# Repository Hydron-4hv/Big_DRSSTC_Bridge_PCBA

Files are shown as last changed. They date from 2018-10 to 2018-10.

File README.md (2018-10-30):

# Big_DRSSTC_Bridge_PCBA
PCBA for 2x IGBT brick bridge for my 160mm DRSSTC

This is a PCBA I have designed to accomodate 2x half-bridge IGBTs, either CM300DY-24H or SKM200GB125D (or any which are dimensionally and pinout compatible). The footprints have enlarged pads to accomodate the difference between the CM300s and SKM200s - I only have a couple of CM300s so if I manage to blow them up I'd like flexibility for replacement!

As well as the IGBTs it allows for a variety of bus/decoupling capacitors and bleed resistors:
- 2x 75mm dia. electrolytic capacitors, in series, with bleed resistors. These will need a short external jumper between the innermost mounting holes (would have lost too much copper area if I'd done it on the PCBA).
- 2x RBPS (or similar sized) IGBT snubber capacitors, mounted directly to the IGBT terminals.
- 2x smaller film capacitors with 22.5mm lead spacing.
- 6x 57.5mm * 35mm film capacitors, with 4 pins each at 52.5mm spacing. These are designed to take the bulk of the ripple current, and should fit a variety of 40uF/900-1100V capacitors that are coming up in bulk lots on ebay in europe. In my case I will be using Kemet C4AEOBW5400A3NJs.
- 6x small HV MLCCs in 1812 and 1825 packages. Added as I have some of these available to use, but may not be very necessary/helpful on a coil using IGBT bricks rather than fast TO-247 devices.
- 2x MMC bleed resistors, in series between the two half-bridge outputs.

This board is designed to go with a matching gate drive connector PCBA, see my other repo for this.

As it's cheapest and easiest to get 2 layer 1oz copper PCBs, I have made sure everything is mirrored around the centre of the PCB, allowing for a stack of an odd number of boards, with every second one flipped, to be made and used as one "multi-layer" PCBA. This both reduces the copper resistance and also the inductance of the bridge. I'll be trying this out with a JLCPCB order of 5x0.8mm PCBs for a 4mm thick stack costing ~$25 USD. For people who don't care about the cost ideally it'd be done with 1 PCB of 2oz+ and 3.2mm thickness for rigidity.

Note: See Manufacturing/Reference output folders for gerbers, schematic PDFs, STEP files etc.

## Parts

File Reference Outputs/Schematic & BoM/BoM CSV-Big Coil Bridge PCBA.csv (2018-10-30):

Designator | Comment | Description | Fitted | Footprint | LibRef | Quantity
C1, C2 | 885012209028 | Electrolytic capacitor | Fitted | PEH200YV447BMB2 | Capacitor_Elec | 2
C3, C4, C5, C6, C7, C8 |  |  | Fitted | C4AEOBW5400A3NJ | Capacitor | 6
C9, C10 | RBPS_Snubber_Capacitor_Mech_only |  | Fitted | RBPS_R4_OUTLINE | RBPS_Snubber_Capacitor_Mech_only | 2
C11, C12, C13, C14, C15, C16, C17, C18 | Capacitor |  | Fitted | 1825C, B32653A0224, 1812C | Capacitor | 8
Q1, Q2 | DUAL_IGBT_BRICK | IGBT, DUAL, BRICK | Fitted | CM300/SKM200_DUAL_FOOTPRINT_2 | DUAL_IGBT_BRICK | 2
R1, R2, R3, R4 | Resistor |  | Fitted | Res_Axial_0.6in | Resistor | 4

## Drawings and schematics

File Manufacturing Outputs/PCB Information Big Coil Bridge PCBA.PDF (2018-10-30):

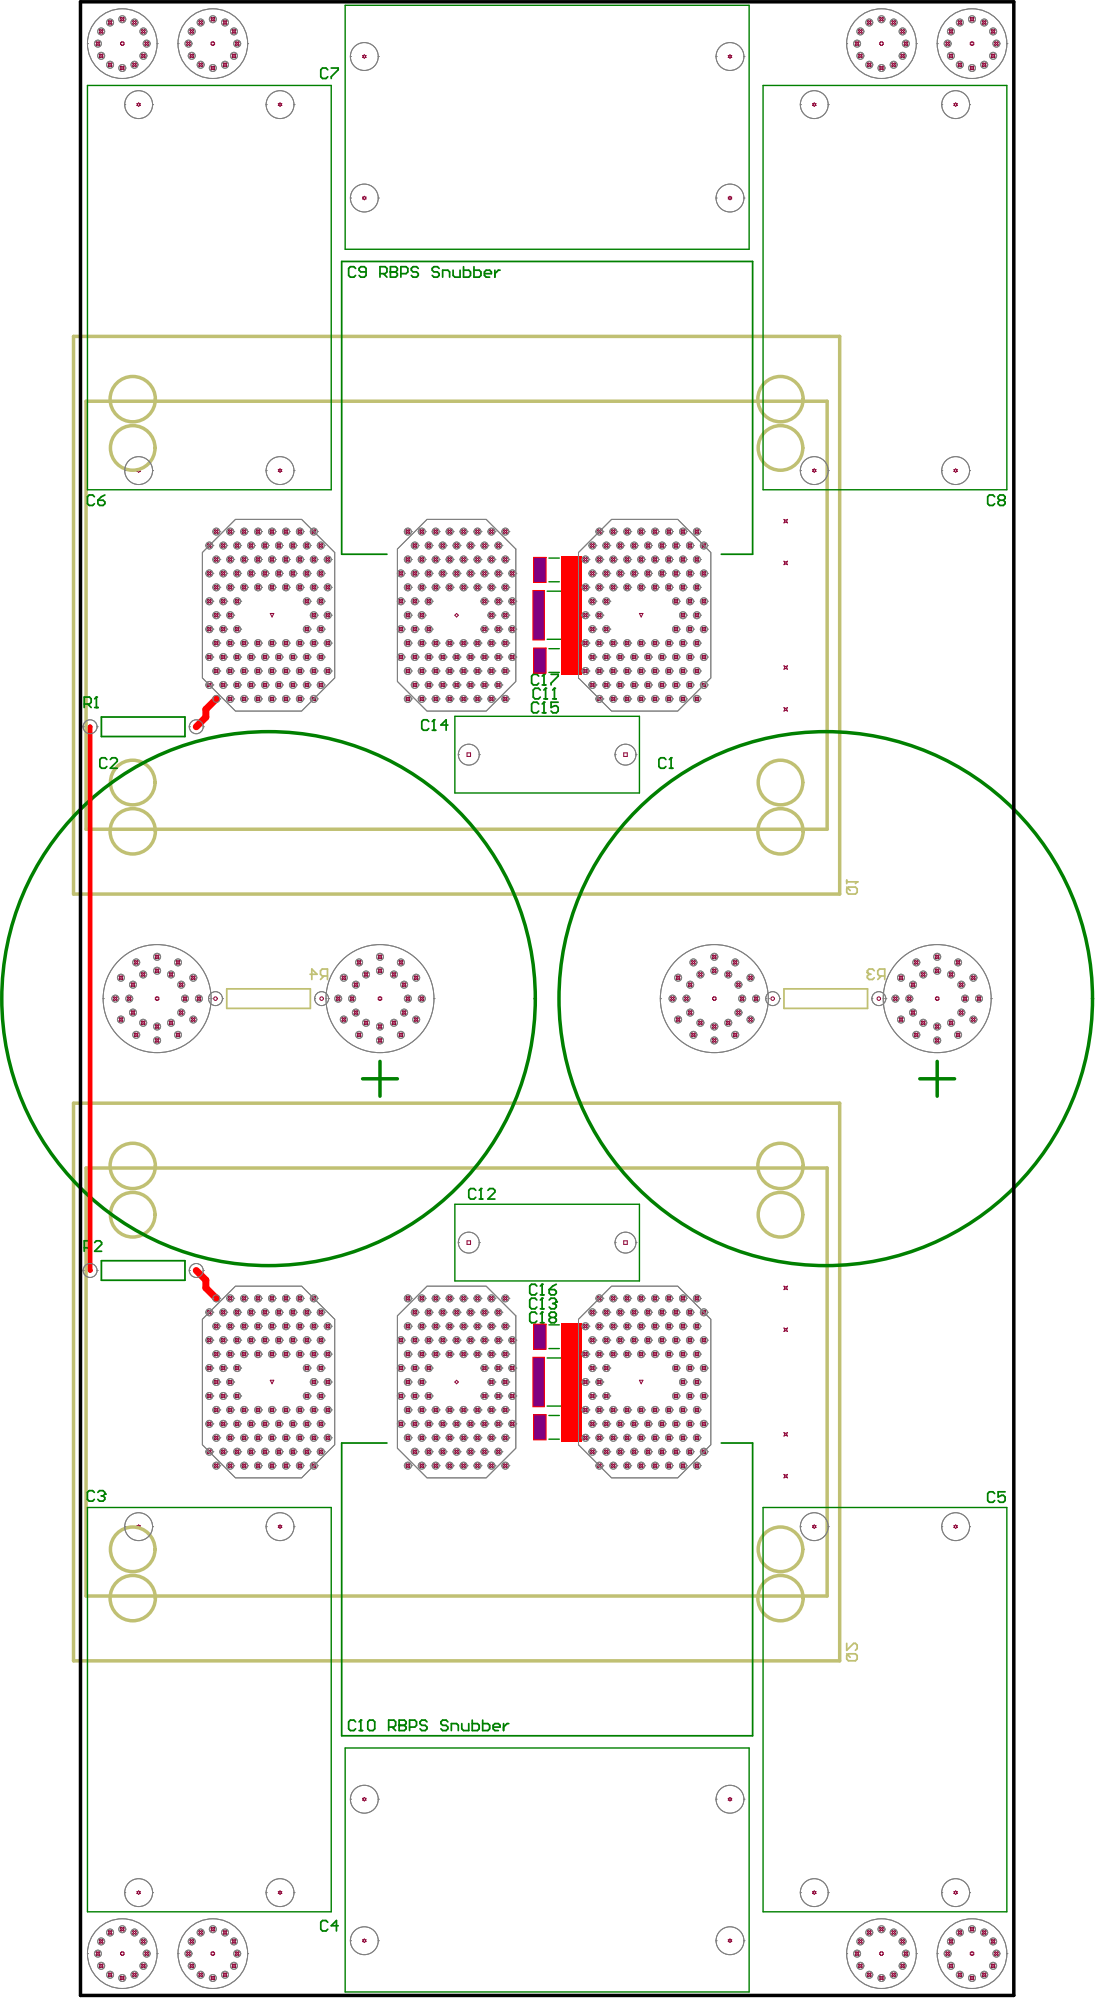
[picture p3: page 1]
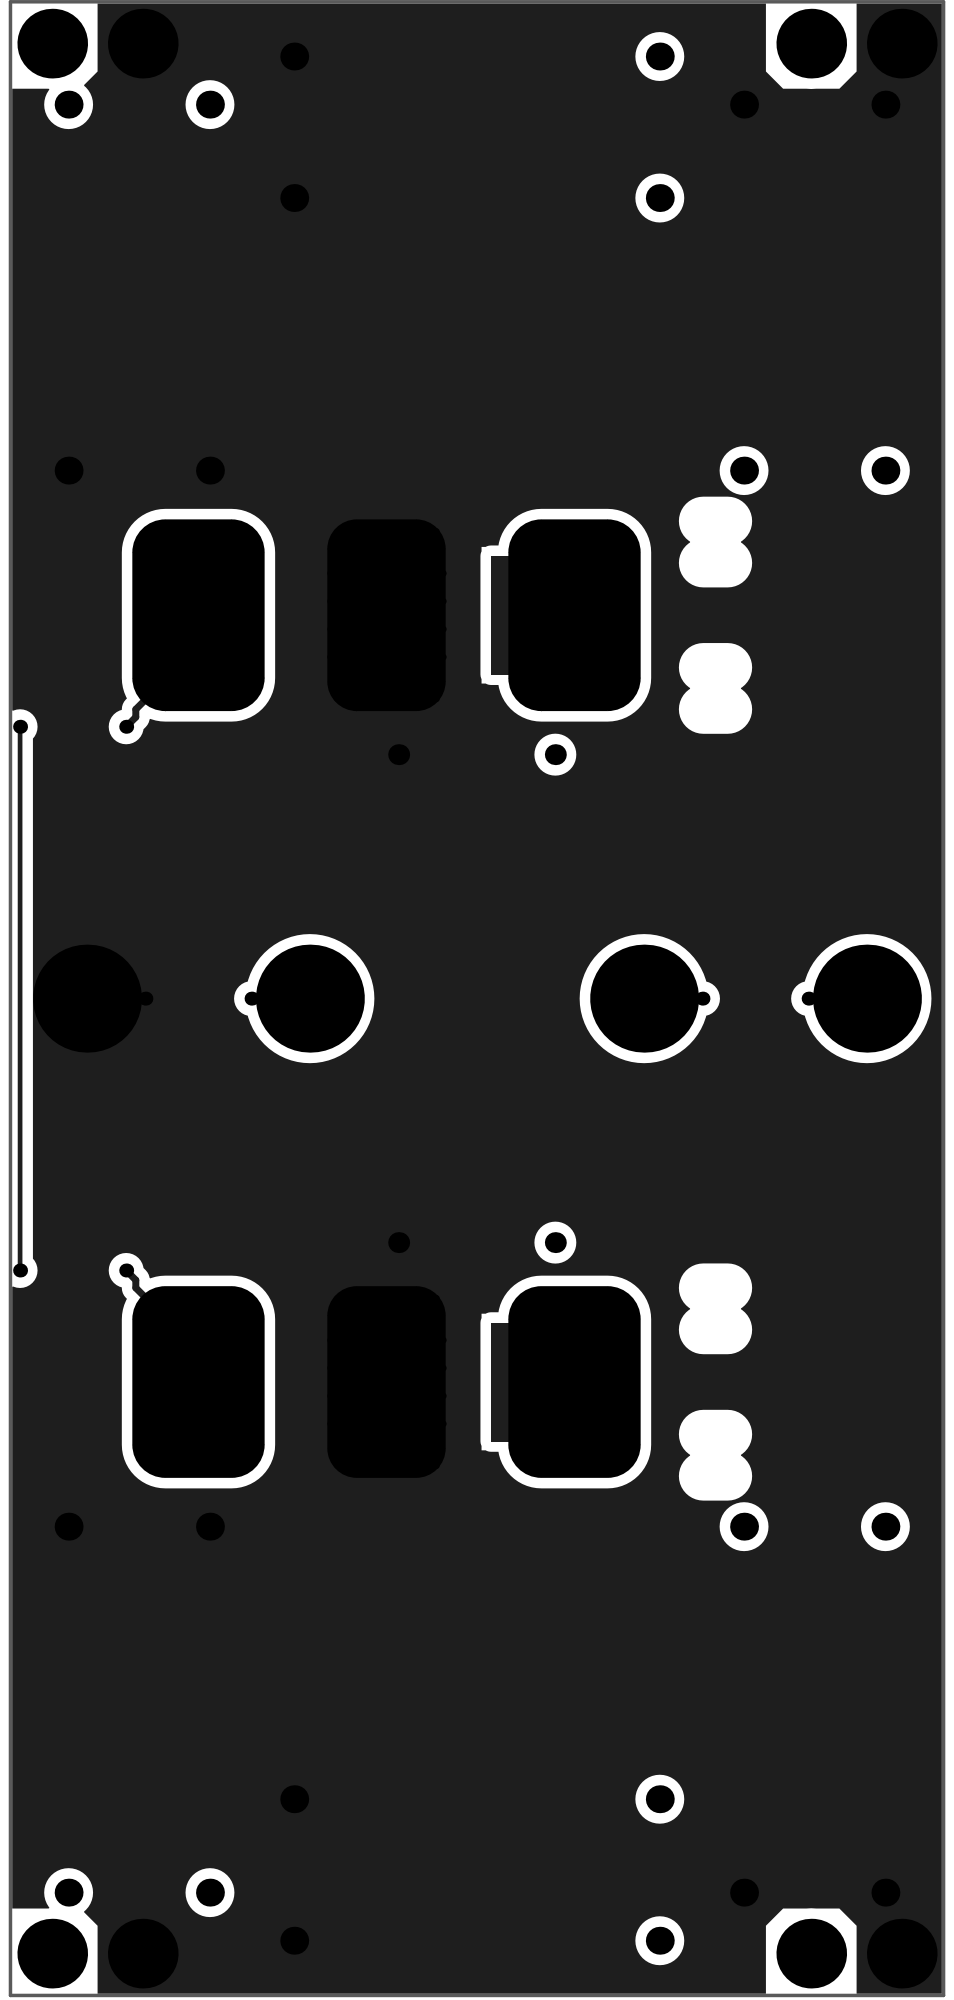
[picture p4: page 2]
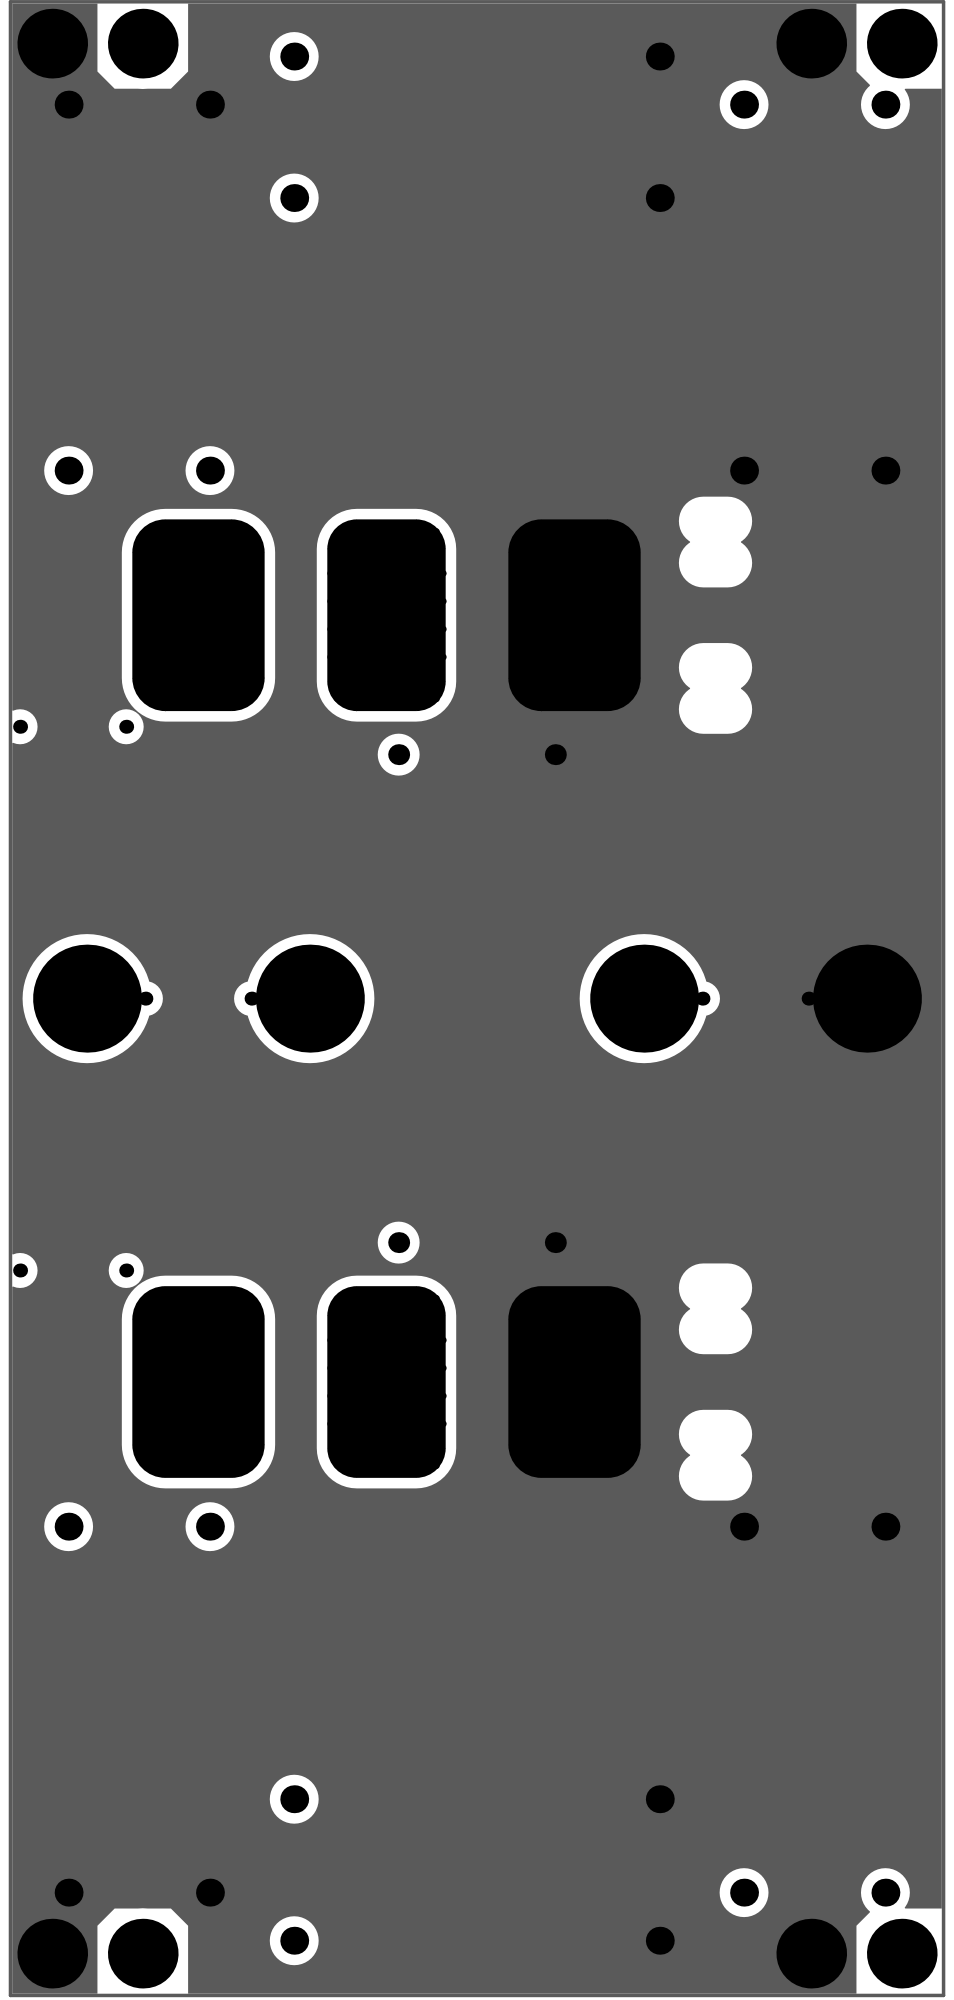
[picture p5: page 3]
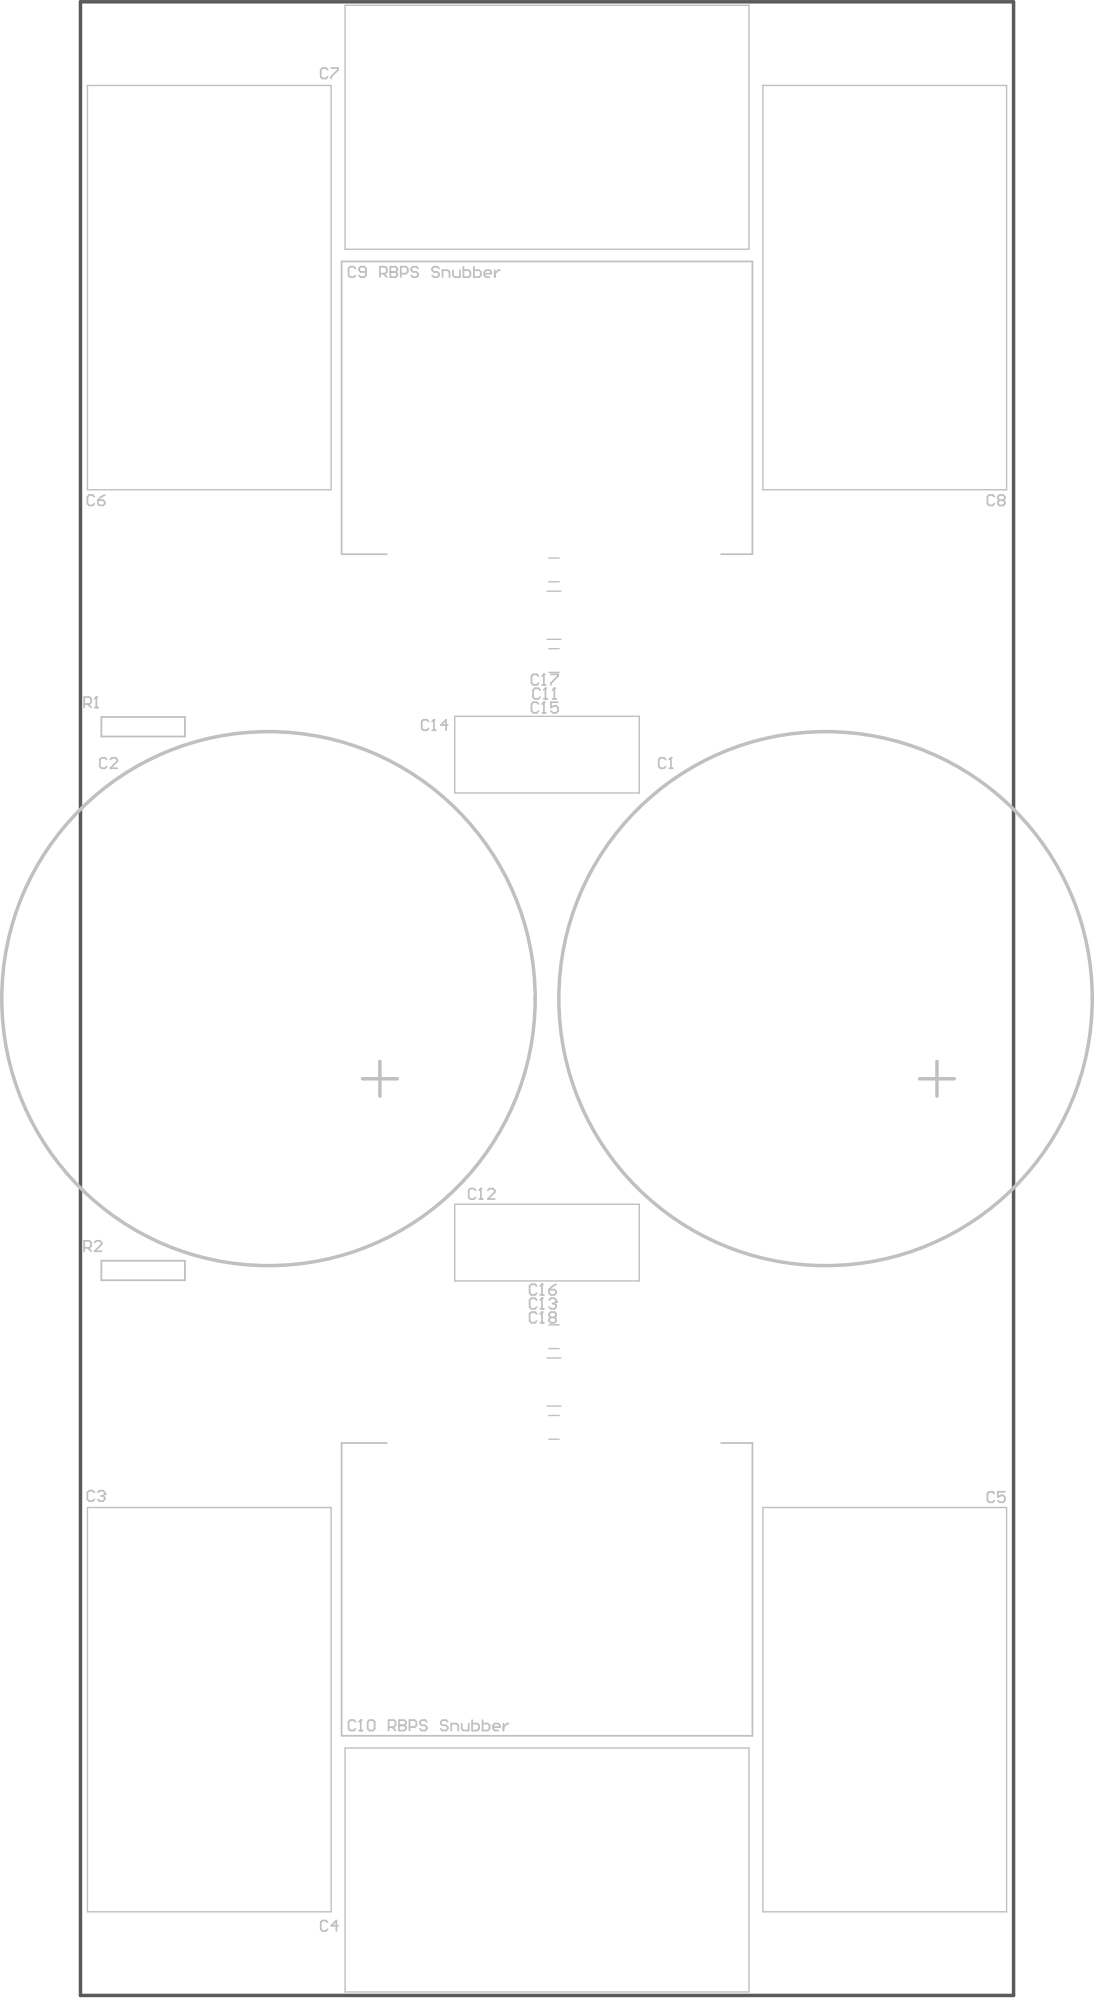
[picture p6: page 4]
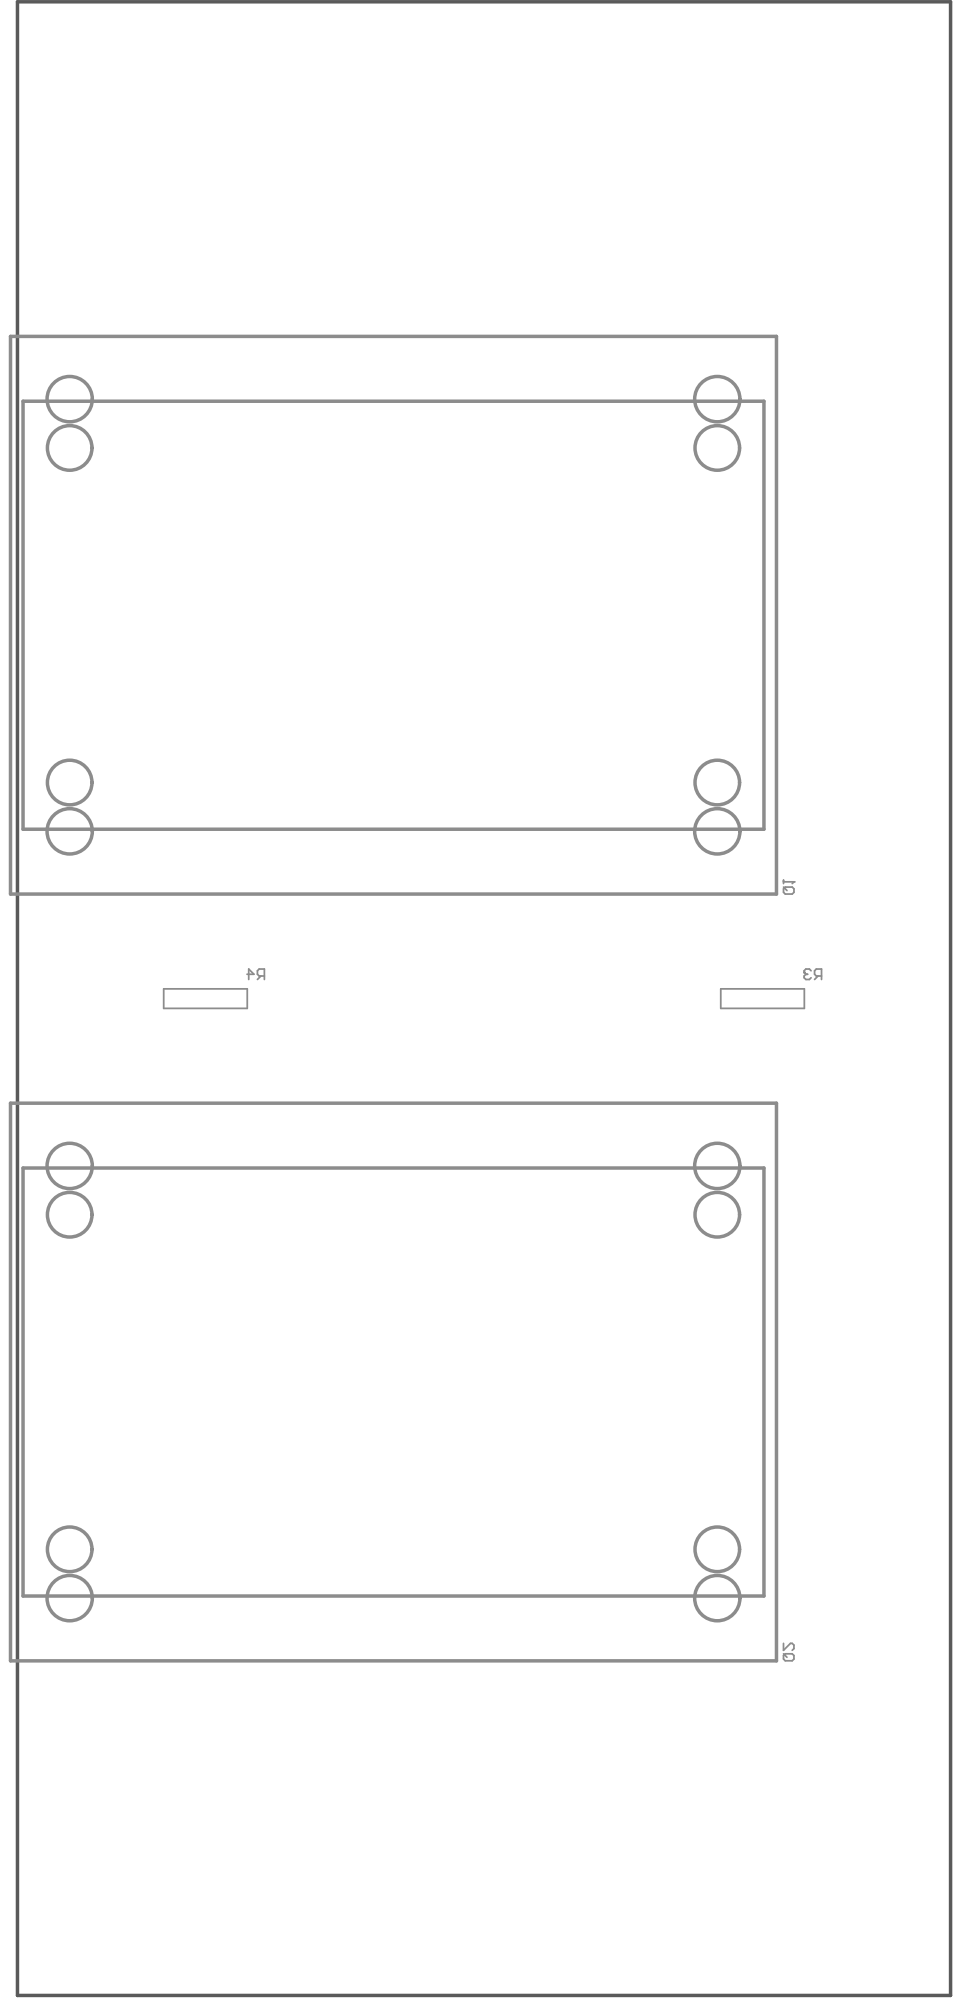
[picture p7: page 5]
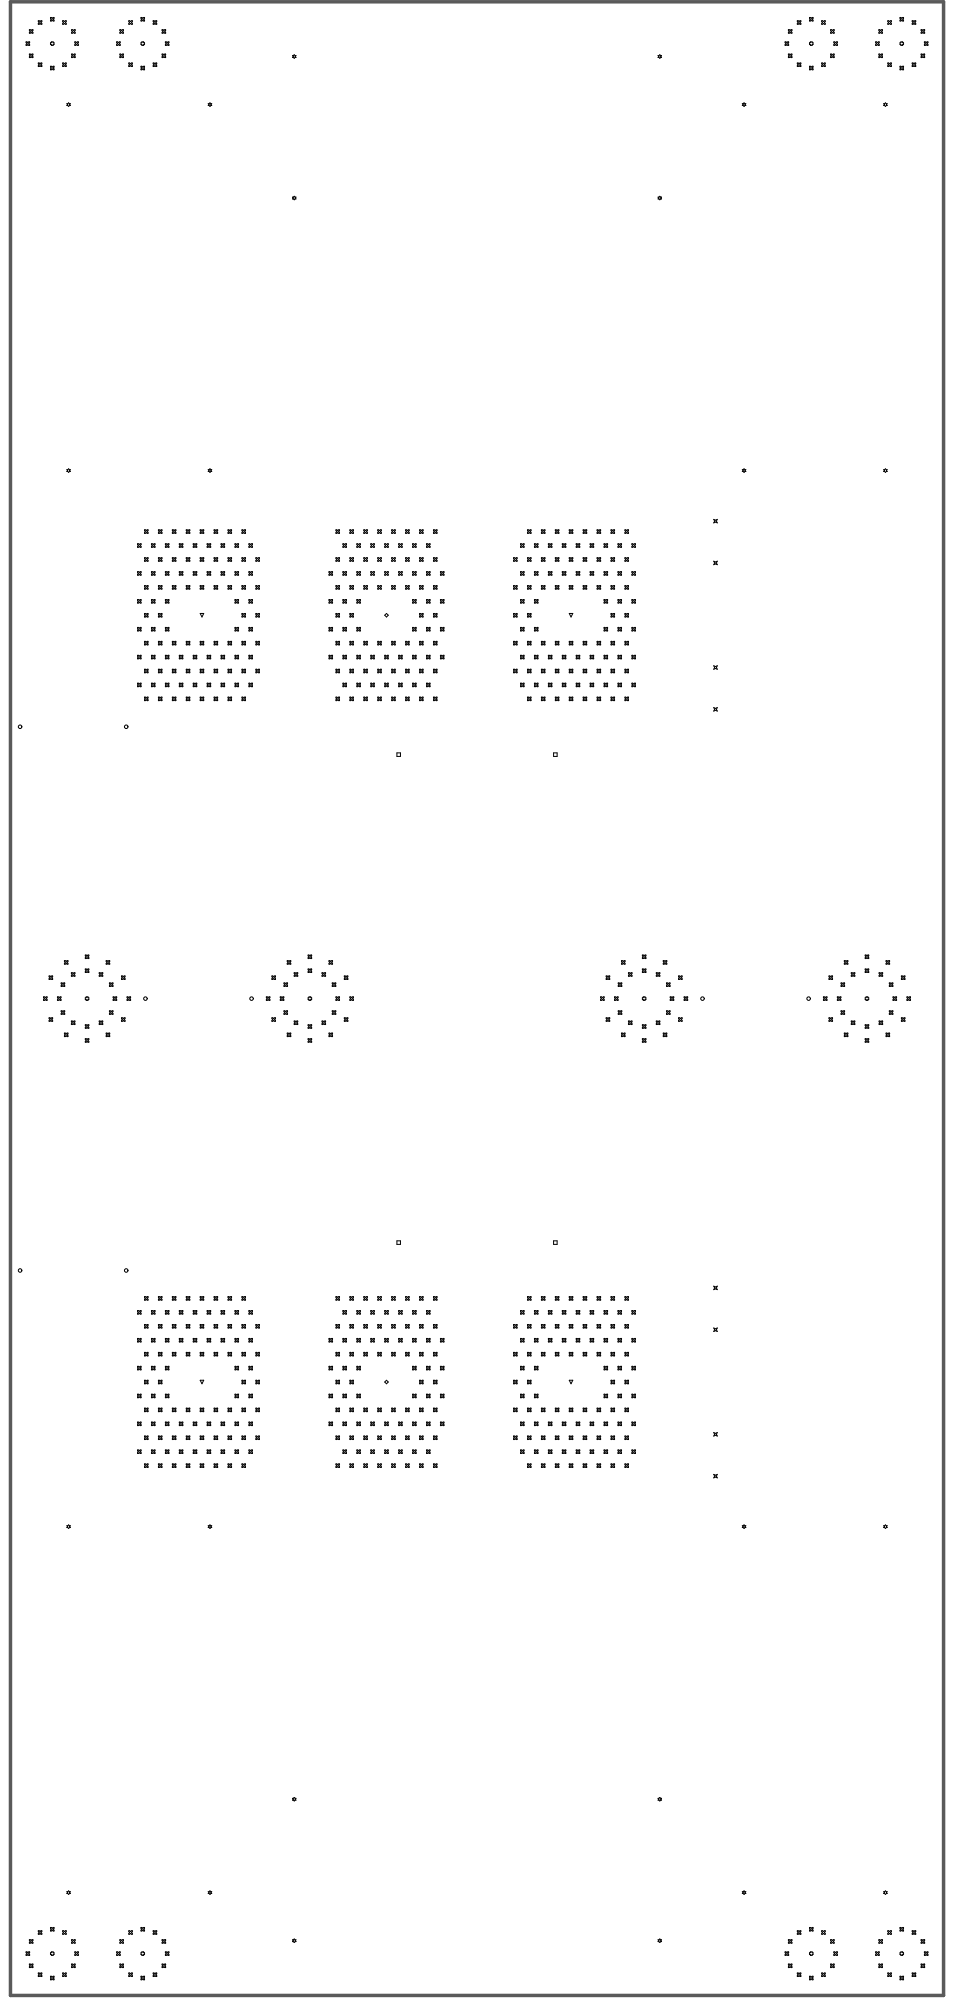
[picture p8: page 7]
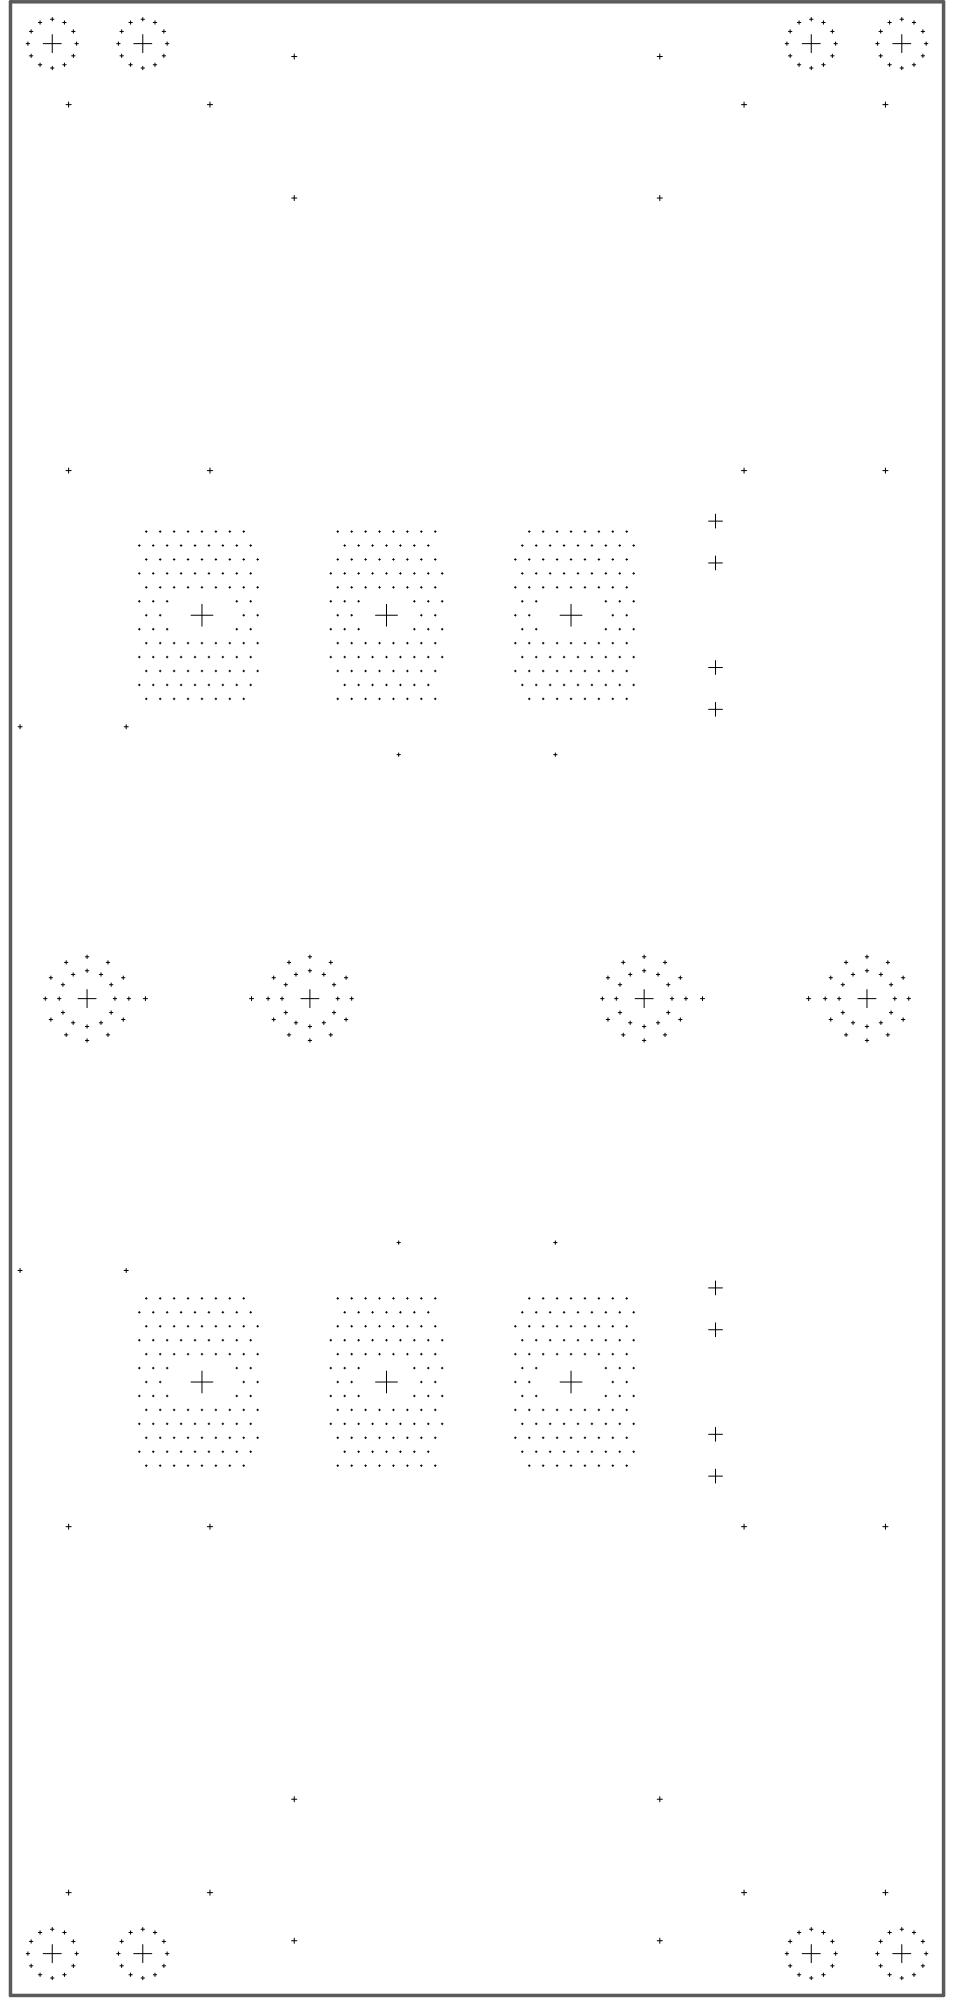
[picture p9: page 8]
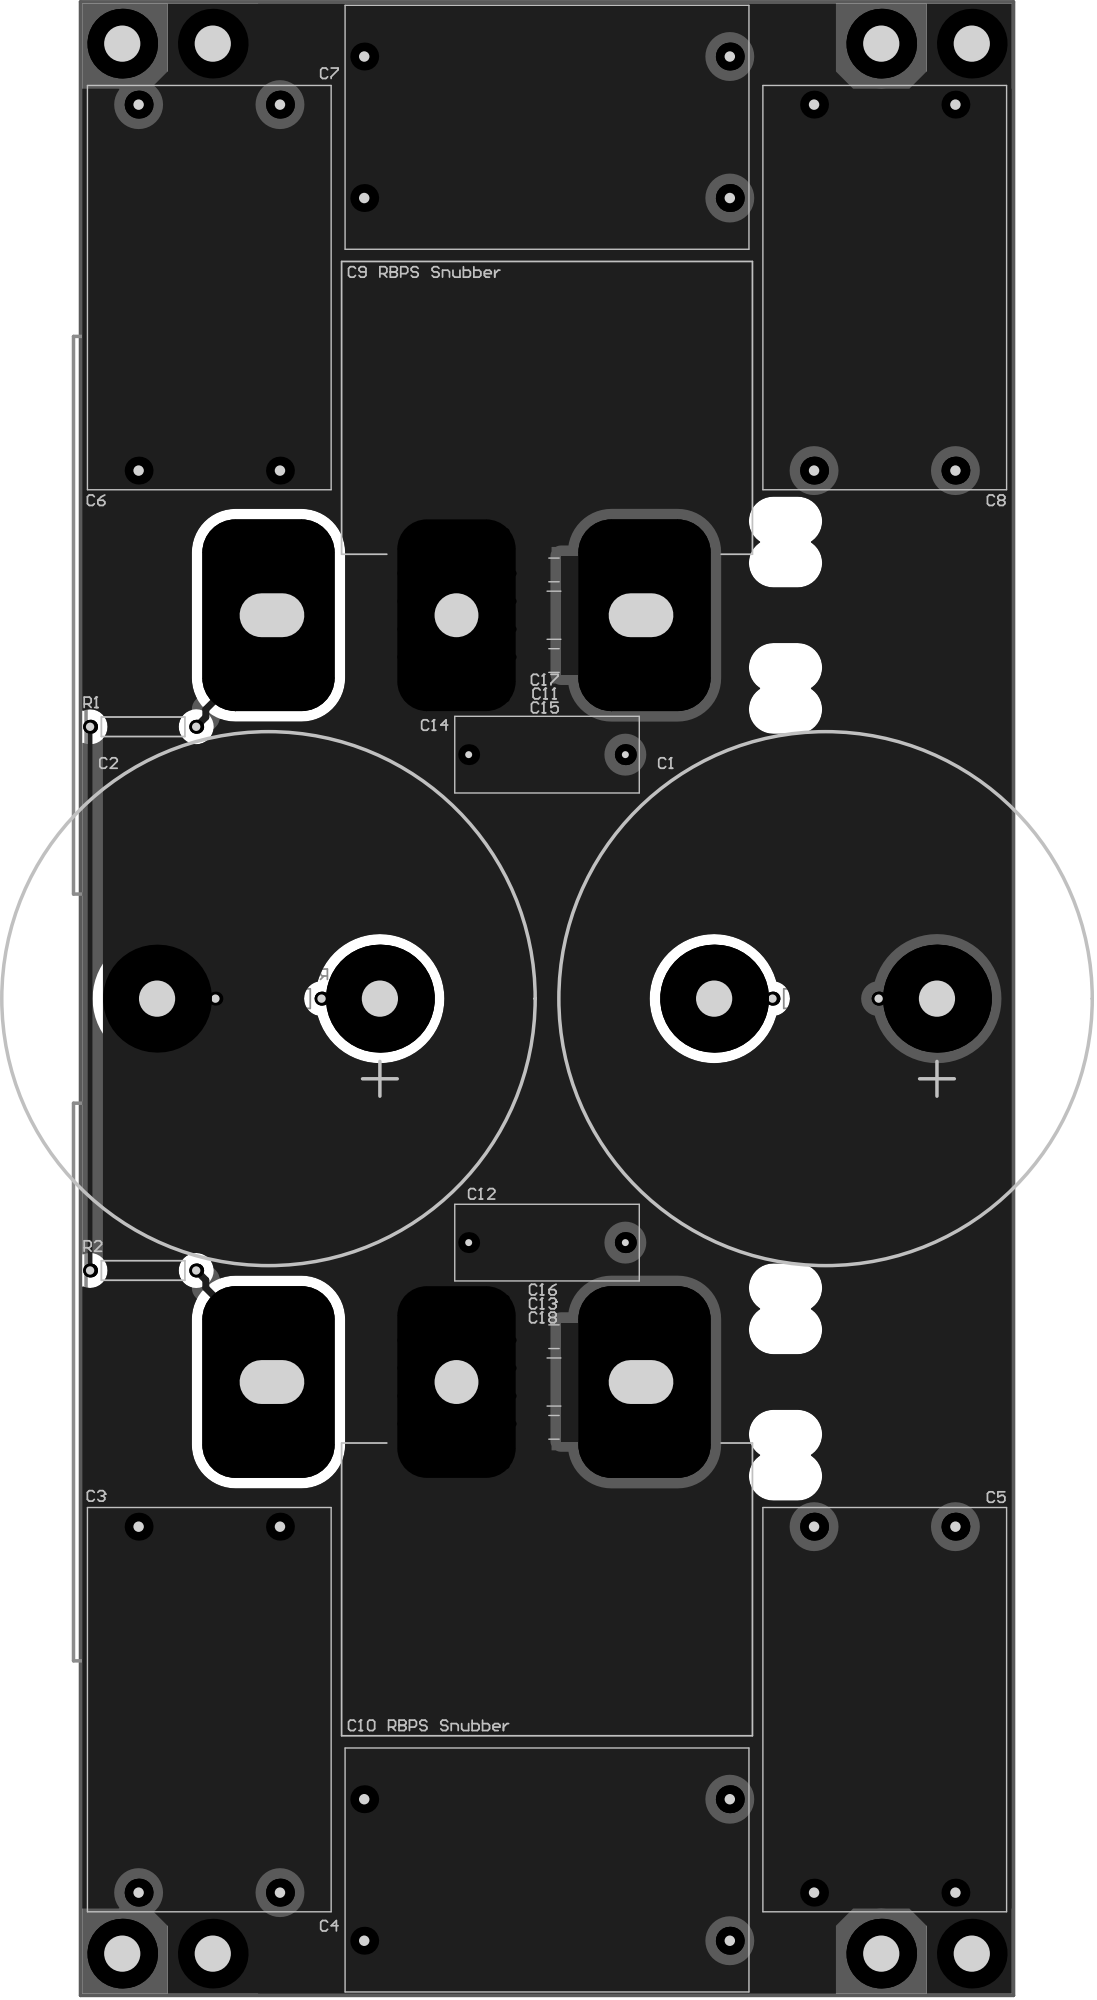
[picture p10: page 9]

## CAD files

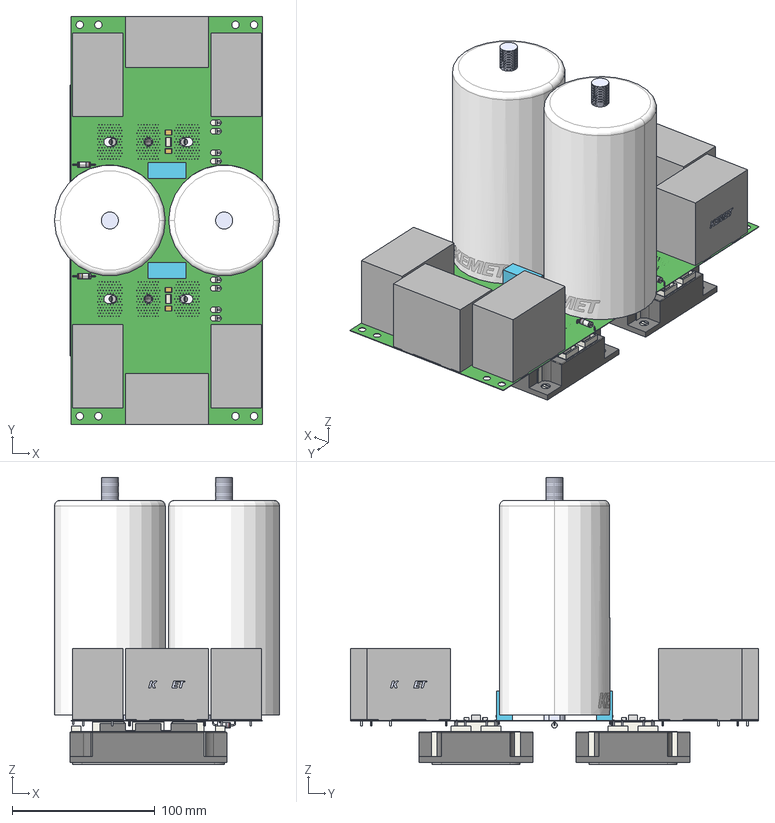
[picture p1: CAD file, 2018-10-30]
Reference Outputs/Mechanical/Export STEP Model of complete PCB_Big Coil Bridge PCBA-([No Variations]).step
157.6 x 286.0 x 200.9 mm
BoardBig_Coil_Bridge_PCBA_2
Open_CASCADE_STEP_translator_6.8_4.1.1 x 4
Open_CASCADE_STEP_translator_6.8_4.1.2 x 4
Open_CASCADE_STEP_translator_6.8_4.2.1 x 4
Extruded x 8
User_Library-Resistor_Carvao_2W_leed x 4
User_Library-Resistor_Carvao_2W_leed1 x 4
User_Library-Resistor_Carvao_2W_Cylinder003 x 4
User_Library-Resistor_Carvao_2W_Cylinder004 x 4
User_Library-Resistor_Carvao_2W_Torus x 4
User_Library-Resistor_Carvao_2W_Torus001 x 4
User_Library-Resistor_Carvao_2W_fx_1 x 4
User_Library-Resistor_Carvao_2W_fx_2 x 4
User_Library-Resistor_Carvao_2W_fx_3 x 4
User_Library-Resistor_Carvao_2W_fx_tol x 4
User_Library-Resistor_Carvao_2W_Cylinder005 x 4
User_Library-Resistor_Carvao_2W_Cylinder006 x 4
User_Library-Resistor_Carvao_2W_Cylinder007 x 4
User_Library-Resistor_Carvao_2W_Fillet x 4
User_Library-Resistor_Carvao_2W_Fillet001 x 4
C4AEOBW5400A3NJ x 6
Can_21 x 2
Oval_Terminal_21 x 4
Stud x 2
User_Library-IGBT_CM600DY-12NF x 2
99437A165 x 6

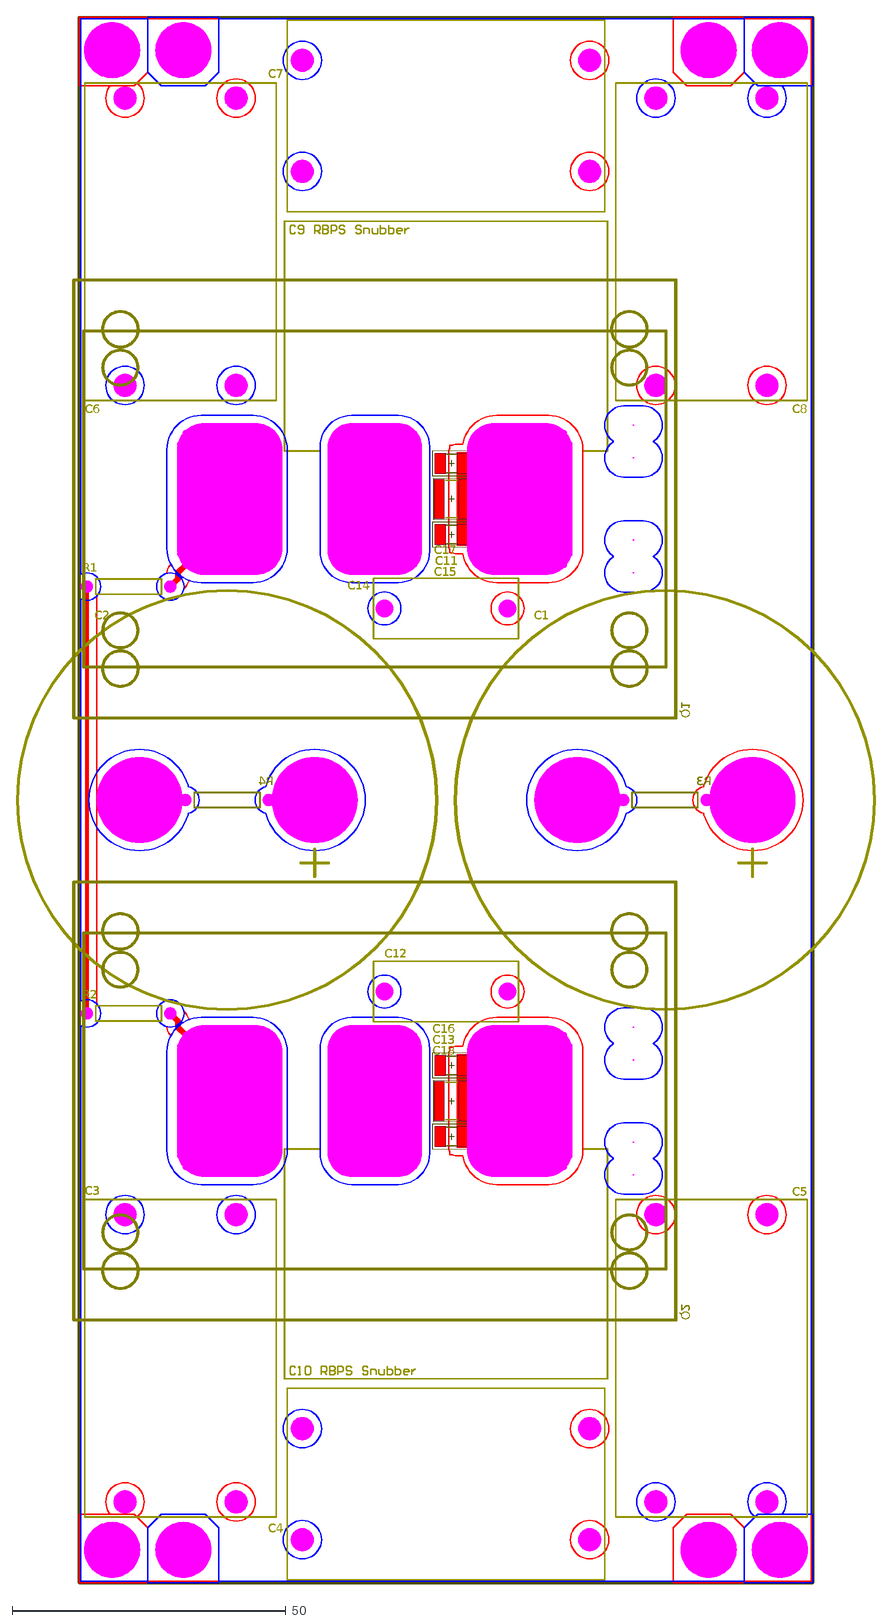
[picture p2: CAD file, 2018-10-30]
Reference Outputs/Mechanical/Big Coil Bridge PCBA_2.DXF
C18
C17
C16
C15
C13
C11
R4
R3
R1
R2
C14
C12
C8
C7
C6
C5
C4
C3
C2
C1
Q2
Q1
